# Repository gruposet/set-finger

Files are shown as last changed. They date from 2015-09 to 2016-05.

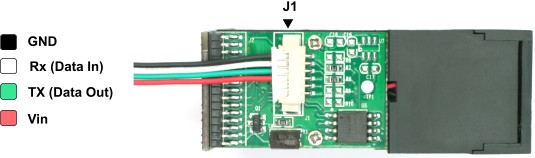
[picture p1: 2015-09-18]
software/codes/arduino/tests/fingerprint/ZFM-206SA_04.jpg

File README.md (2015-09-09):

# set-finger

GRUPO DE TRABALHO - SET

PROJETO SET-FINGER:

SET-FINGER é um projeto desenvolvido pelo Grupo de Trabalho - SET, com a
solução de uma tranca elétrica por biometria para segurança do espaço de
trabalho dos desenvolvedores e colaboradores do SET.

DESCRIÇÃO:

Os principais componentes do projeto são um Arduino Mega, um sensor
Biométrico, um teclado (4x3), shield Ethernet, relé, buzzer, display LCD
e um LED.

O repositório é composto pelos diretórios arduino code, board, libraries,
nodefinger e schematic. Pelo arquivos componentesSetFinger.pdf e README.txt

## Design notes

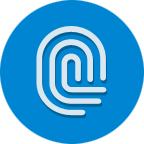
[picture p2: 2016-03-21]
software/codes/setfinger/sf.png

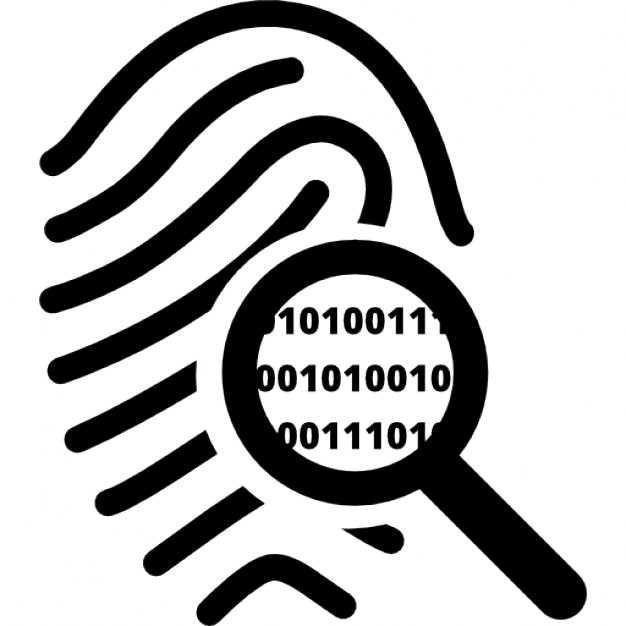
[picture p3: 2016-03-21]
software/codes/setfinger/fingerprint-search-symbol-of-secret-service-investigation_318-64591.png

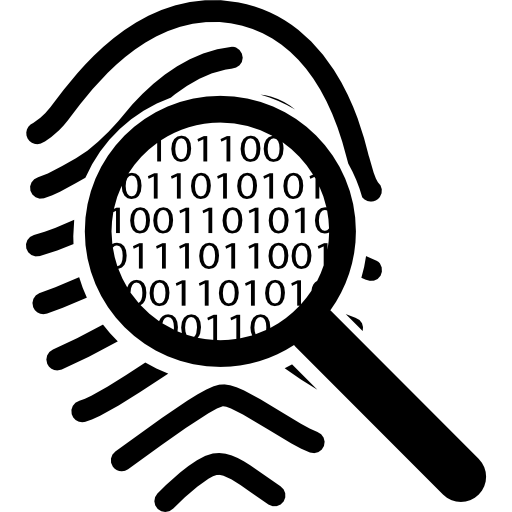
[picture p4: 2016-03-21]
software/codes/setfinger/sf1.png

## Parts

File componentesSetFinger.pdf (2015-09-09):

Componentes Set-Finger:

- Adafruit fingerprint sensor.
- Arduino Ethernet shield r3.
- Arduino mega 2560.
- Buzzer.
- Conetor P4 Fêmea.
- Diodo n4007.
- Display de lcd 16x2 com backlight.
- Fonte regulada 12V.
- Led RGB.
- Relé 5v.
- Resistor 100 ohm.
- Resistor 220 ohm.
- Resistor 2k2 ohm.
- Resistor 330 ohm.
- Resistor 68 ohm.
- Teclado matricial - 12 botões.

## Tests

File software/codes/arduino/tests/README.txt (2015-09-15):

Este diretório contém os diretórios de teste para cada componente do projeto com seus respectivos pinos.

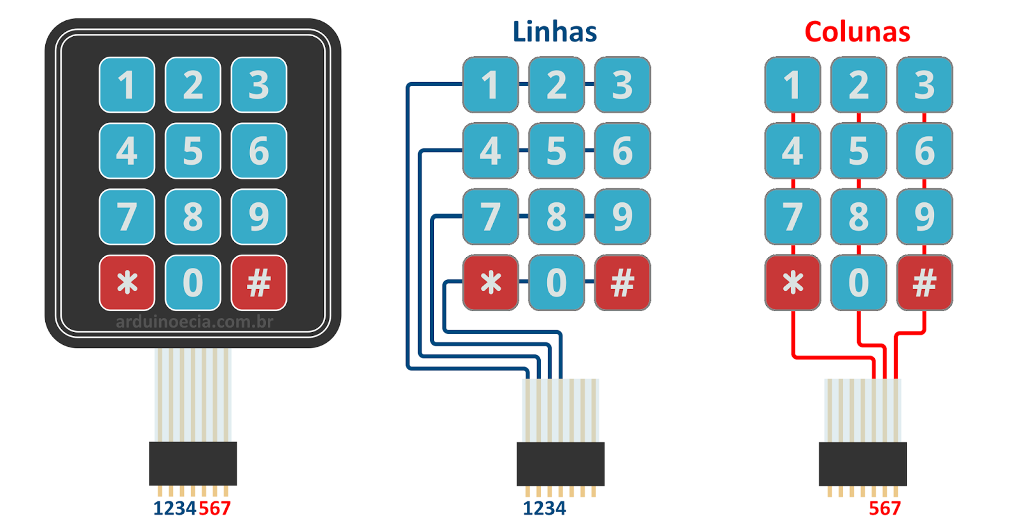
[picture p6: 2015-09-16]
software/codes/arduino/tests/keypad/Teclado_Matricial_4x3_linhas_e_colunas.png

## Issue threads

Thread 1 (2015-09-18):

Sensor fingerprint: Não funciona quando o código arduino é compilado na IDE 2:1.0.5+dfsg2-4

gruposet, 2015-09-18:
O sensor fingerprint não funciona quando o código é compilado e feito upload na IDE Arduino 2:1.0.5+dfsg2-4, apesar de não apresentar nenhum erro na compilação e upload. No entanto, percebemos que em outras versões da IDE Arduino o sensor funciona normalmente.

Closed 2015-09-18.

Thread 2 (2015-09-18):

Sensor fingerprint: Não funciona quando o código arduino é compilado na IDE 2:1.0.5+dfsg2-4

jeffersonfpalheta, 2015-09-18:
O sensor fingerprint não funciona quando o código é compilado e feito upload na IDE Arduino 2:1.0.5+dfsg2-4, apesar de não apresentar nenhum erro na compilação e upload. No entanto, percebemos que em outras versões da IDE Arduino o sensor funciona normalmente.

kelvinmaues, 2015-09-18:
Eu encontrei este fórum sobre o problema, não sei se ajuda.
http://forums.adafruit.com/viewtopic.php?f=25&t=38044&start=0

lucaslg26, 2015-09-20:
É uma package marcada como "unstable".
Para esse tipo de situação, evitem o uso de repositórios, ppa's e afins.
Baixem sempre o último build 'stable' do site oficial! :)

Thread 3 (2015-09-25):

Erro de impressão de mensagem no monitor serial Arduino

jeffersonfpalheta, 2015-09-25:
O código a seguir (Figura 1) executa a função [test( )] que retorna uma string. No loop é declarada uma variável que recebe o retorno da função teste e sem seguida esta variável é impressa na serial. No entanto, observasse um erro (Figura 2) na impressão da variável quando a função finger.getImage( ) é executada. O erro só é evitado de duas maneira:

[Solução 1]
Mudar o formato de retorno da função test( ) para [uint8_t], declarando assim: uint8_t test( )

[Solução 2]
Eliminar a função [finger.getImage( )]. Sem a execução desta função, a impressão da variável de retorno ocorre normalmente.

Figura 1 (código)
![Image of imagem5]
(https://lh3.googleusercontent.com/-fTIWpGMoyPE/VgVlG44bOpI/AAAAAAAABN8/QSN2o3Lke-I/s800-Ic42/imagem5.png)

Figura 2 (ERRO)
![Image of imagem6]
(https://lh3.googleusercontent.com/-EUJfj0hAlMU/VgVlIW_e6kI/AAAAAAAABOE/OPkDEjtmZUg/s800-Ic42/imagem6.png)

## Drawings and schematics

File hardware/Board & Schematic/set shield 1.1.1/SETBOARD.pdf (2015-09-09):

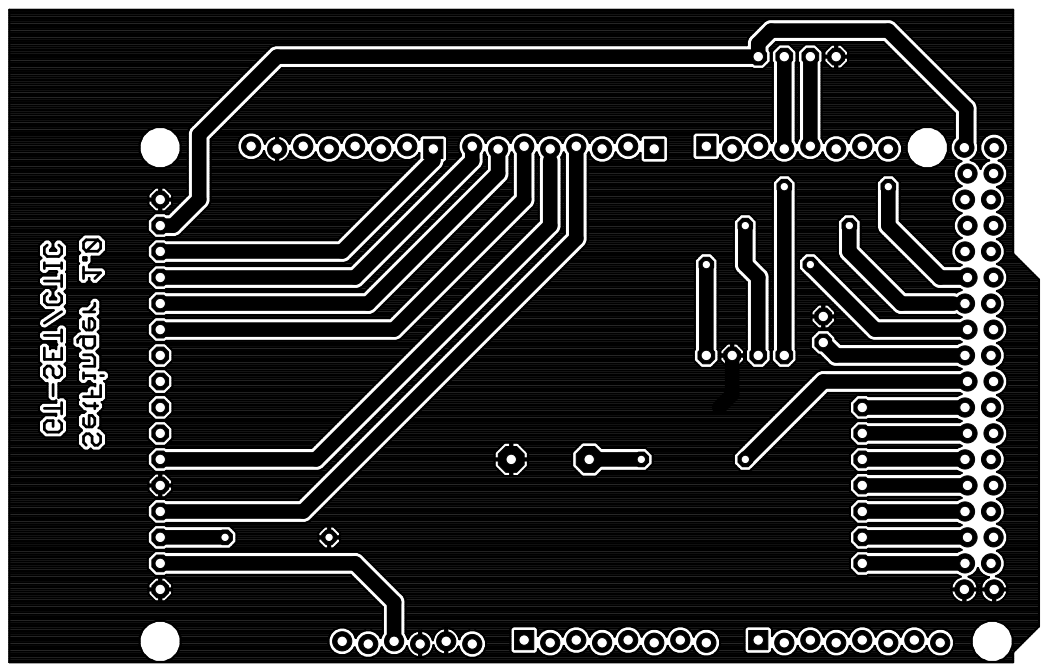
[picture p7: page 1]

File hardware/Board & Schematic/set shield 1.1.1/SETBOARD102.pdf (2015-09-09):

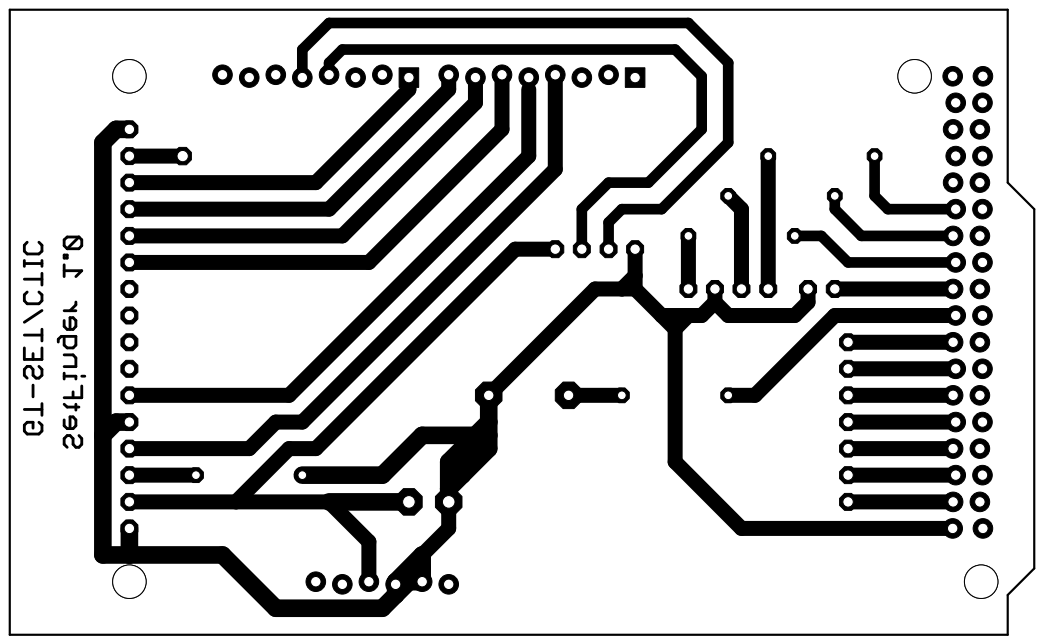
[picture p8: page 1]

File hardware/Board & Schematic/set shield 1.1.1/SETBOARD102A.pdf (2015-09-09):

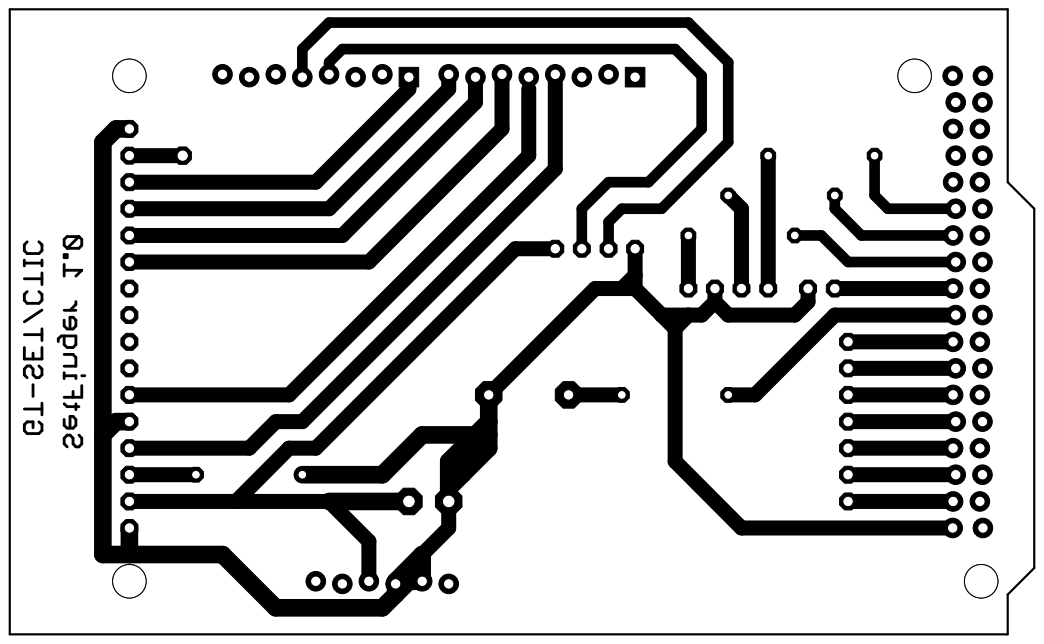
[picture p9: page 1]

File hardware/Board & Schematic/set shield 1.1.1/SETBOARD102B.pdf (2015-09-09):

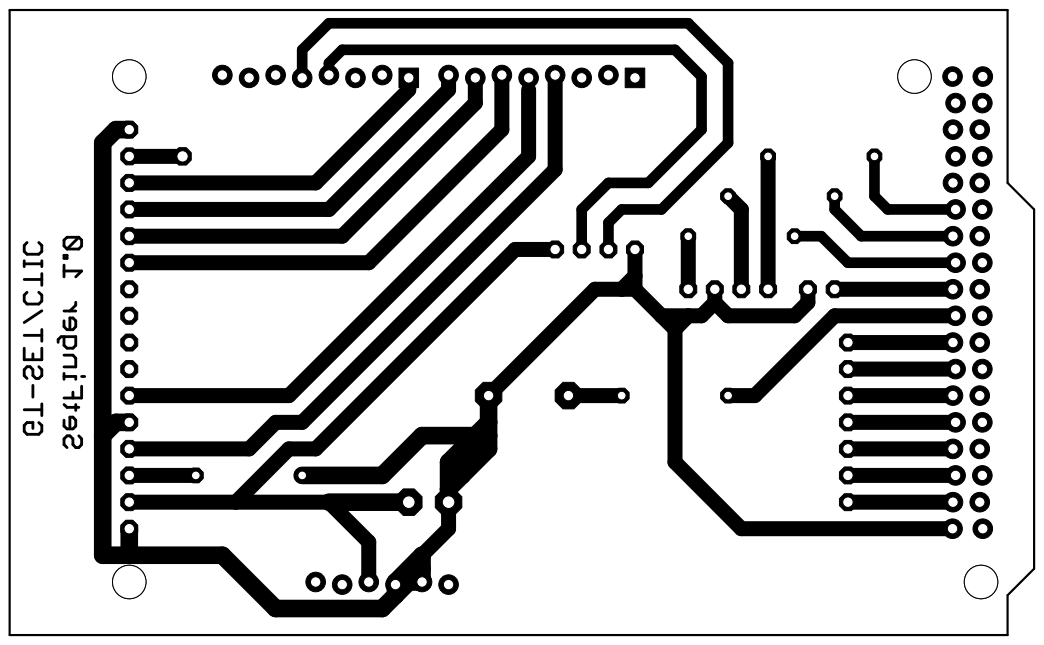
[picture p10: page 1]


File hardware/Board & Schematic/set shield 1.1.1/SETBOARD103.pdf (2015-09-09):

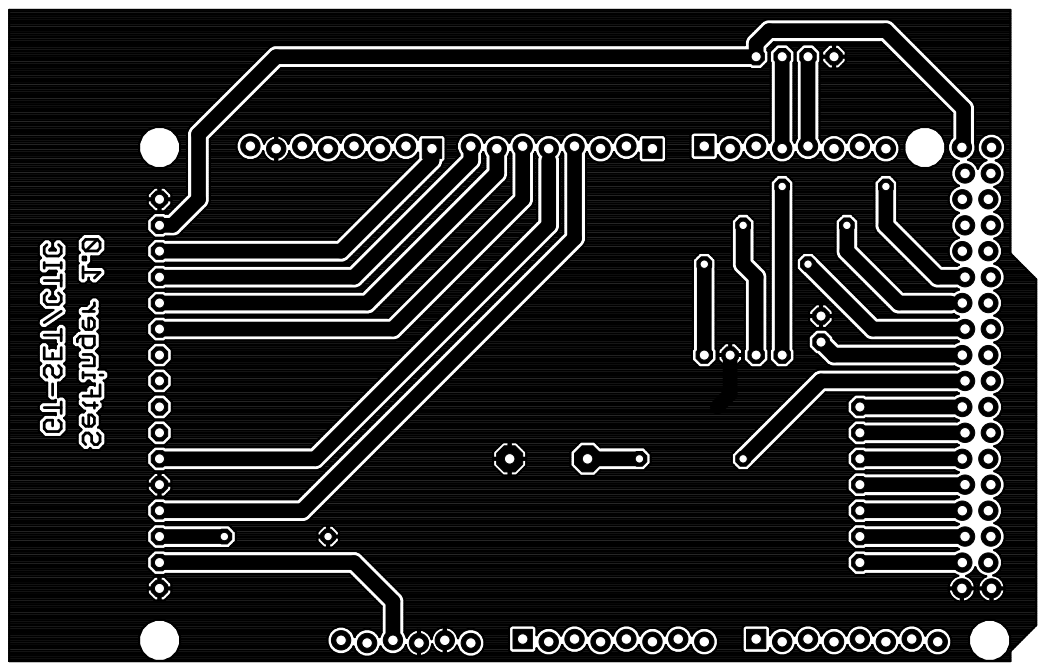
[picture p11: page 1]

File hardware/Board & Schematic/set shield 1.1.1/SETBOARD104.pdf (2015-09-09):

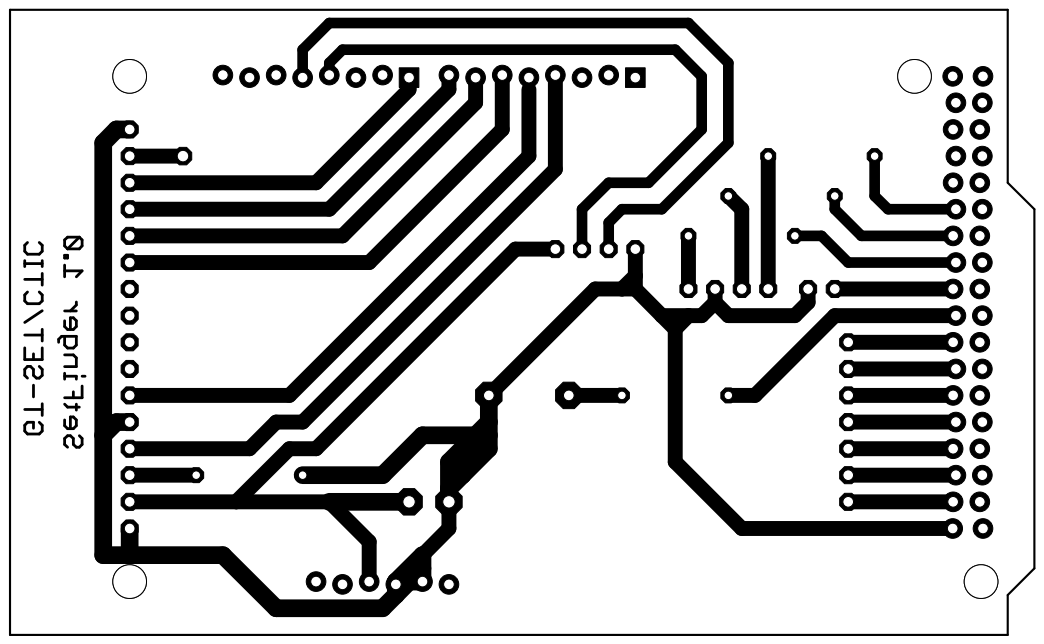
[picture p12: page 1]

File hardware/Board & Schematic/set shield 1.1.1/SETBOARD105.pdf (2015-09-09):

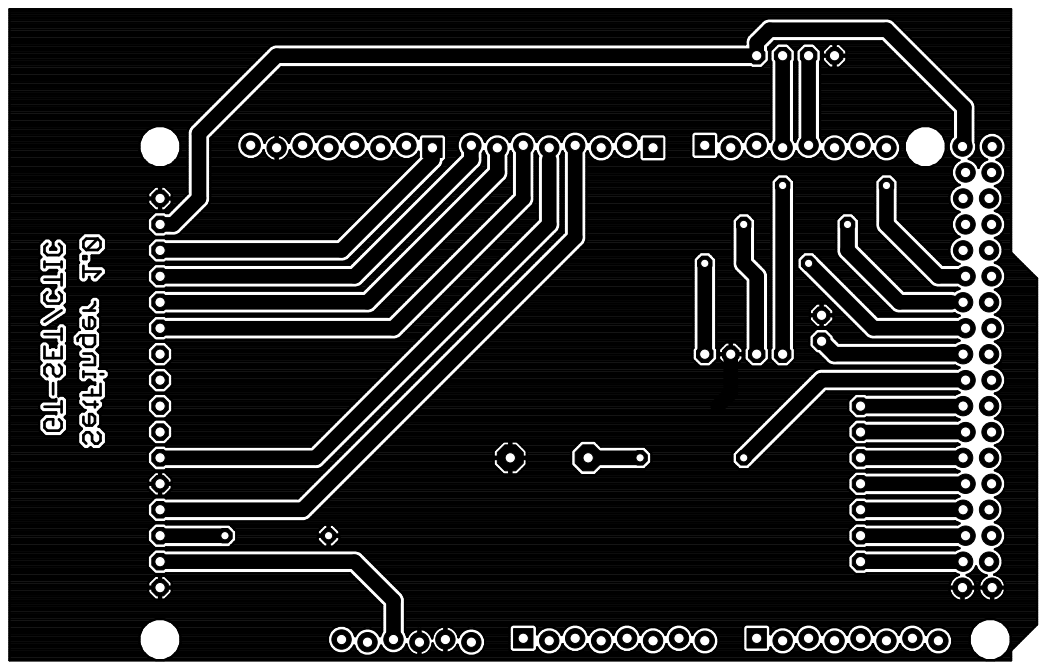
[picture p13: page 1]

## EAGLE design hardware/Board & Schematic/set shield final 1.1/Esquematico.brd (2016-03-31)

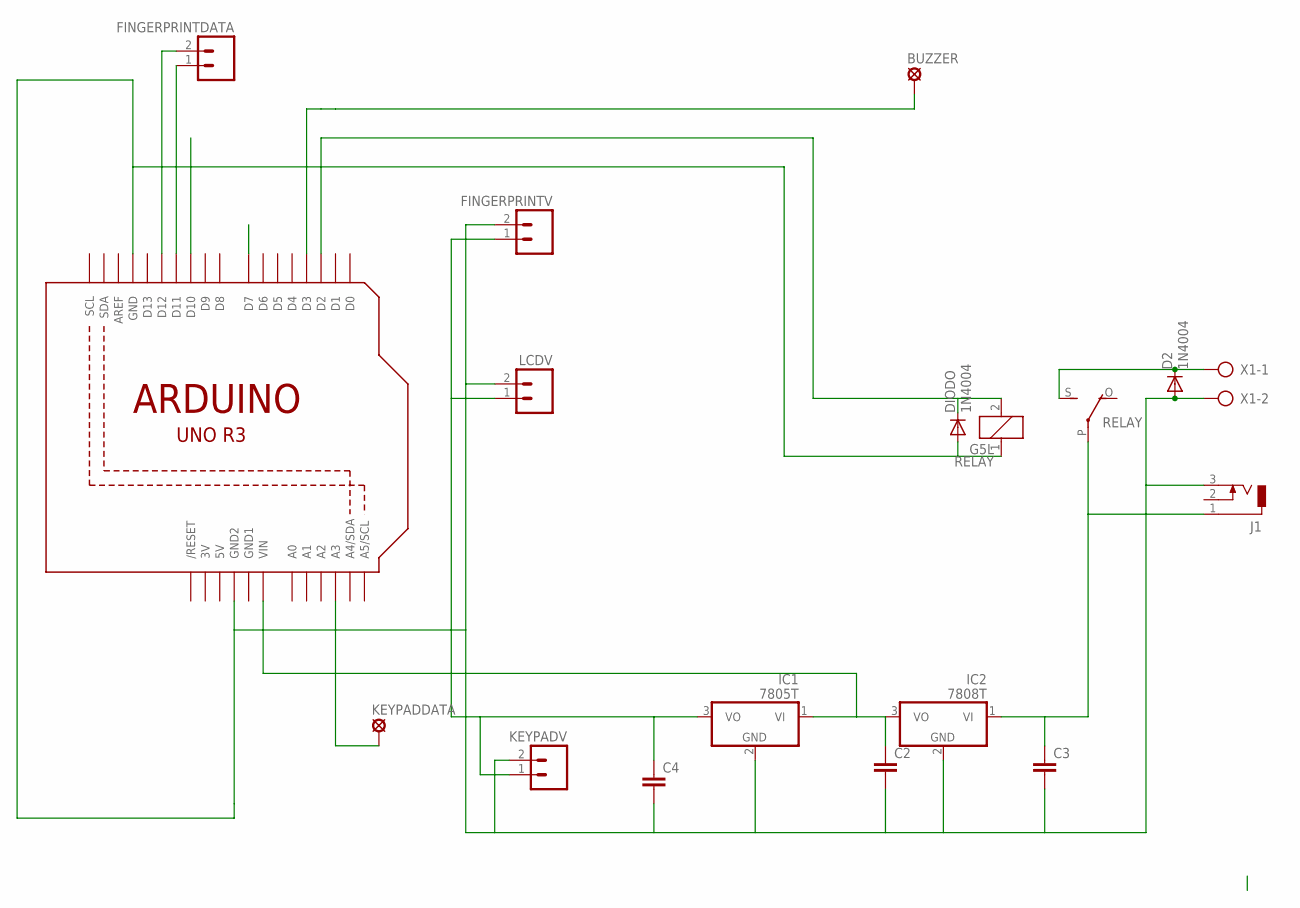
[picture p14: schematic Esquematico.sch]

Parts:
BUZZER: SE14
C2, C3, C4: C-EU025-030X050; C025-030X050
D2: 1N4004; DO41-10
DIODO: 1N4004; DO41-10
FINGERPRINTDATA: M02; 02P
FINGERPRINTV: M02; 02P
IC1: 7805T; TO220H
IC2: 7808T; TO220H
J1: DCJ0303
KEYPADDATA: SE14
KEYPADV: M02; 02P
LCDV: M02; 02P
Q1: ARDUINOR3-NOIOREF-NOTEXT; ARDUINOR3-NOTEXT-NOIOREF
RELAY: G5L; G5LE
X1: AK300/2

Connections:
3V: Q1.3V
5V: Q1.5V
GND1: Q1.GND1
unnamed: FINGERPRINTDATA.2, Q1.D12
unnamed: FINGERPRINTDATA.1, Q1.D11
unnamed: D2.C, RELAY.S, X1.1
unnamed: KEYPADDATA.MP, Q1.A3
unnamed: BUZZER.MP, Q1.D3
unnamed: C4.1, FINGERPRINTV.1, IC1.3 (VO), KEYPADV.1, LCDV.1
unnamed: DIODO.C, Q1.D2, RELAY.2
unnamed: DIODO.A, Q1.GND, RELAY.1
unnamed: C2.2, C3.2, C4.2, D2.A, FINGERPRINTV.2, IC1.2 (GND), IC2.2 (GND), J1.3, KEYPADV.2, LCDV.2, Q1.GND2, X1.2
unnamed: C2.1, IC1.1 (VI), IC2.3 (VO), Q1.VIN
unnamed: C3.1, IC2.1 (VI), J1.1, RELAY.P

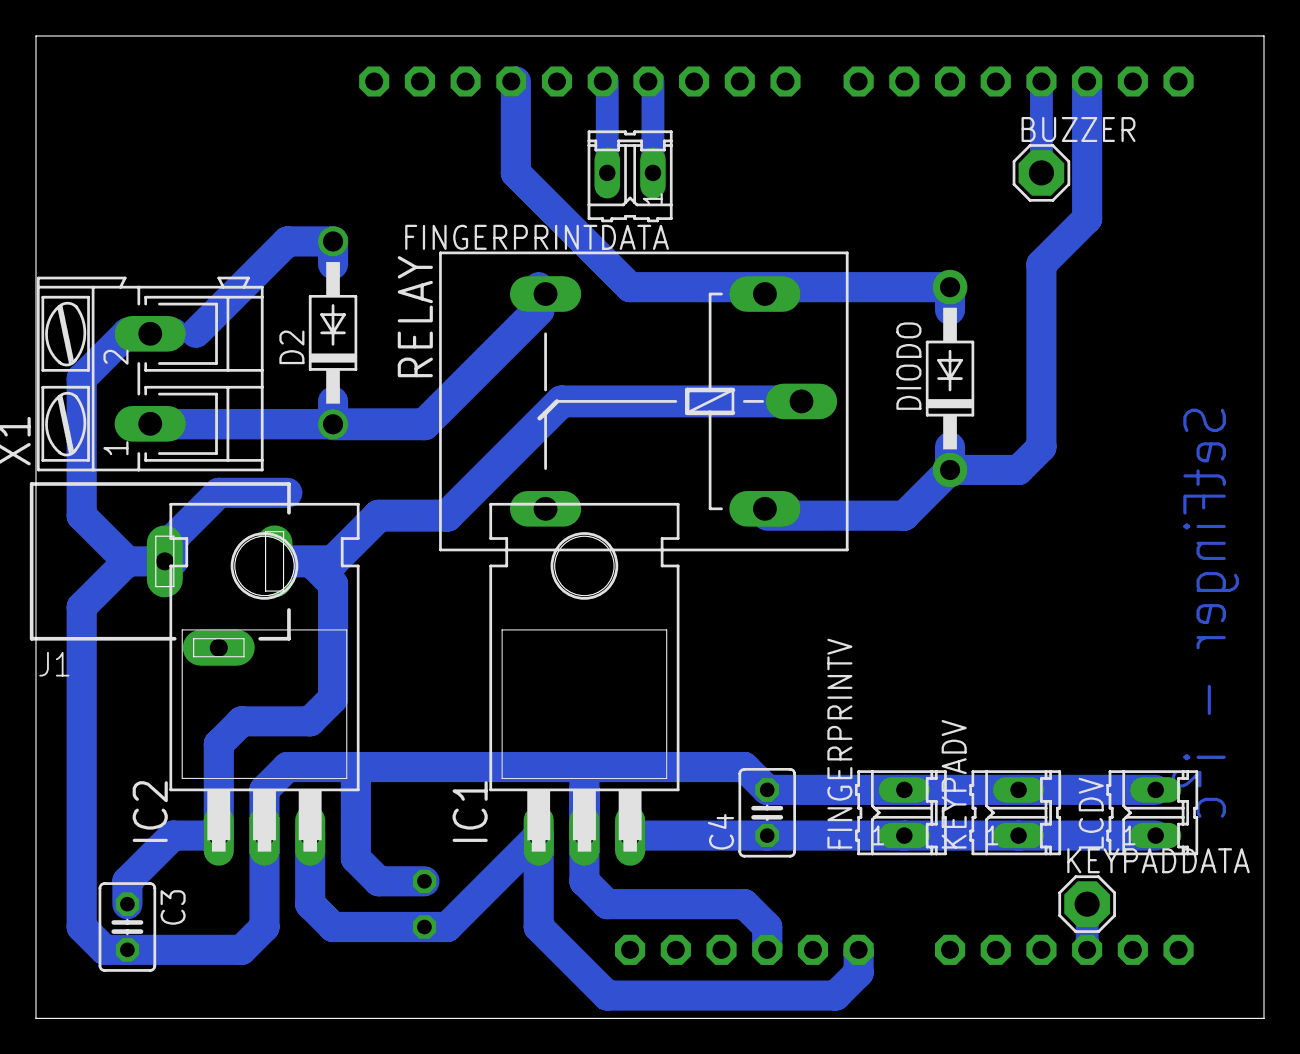
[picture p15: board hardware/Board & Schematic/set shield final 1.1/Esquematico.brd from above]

Board: 2 copper layers, 68.2 x 54.6 mm, 17 parts (1 on the bottom side), 11 nets.

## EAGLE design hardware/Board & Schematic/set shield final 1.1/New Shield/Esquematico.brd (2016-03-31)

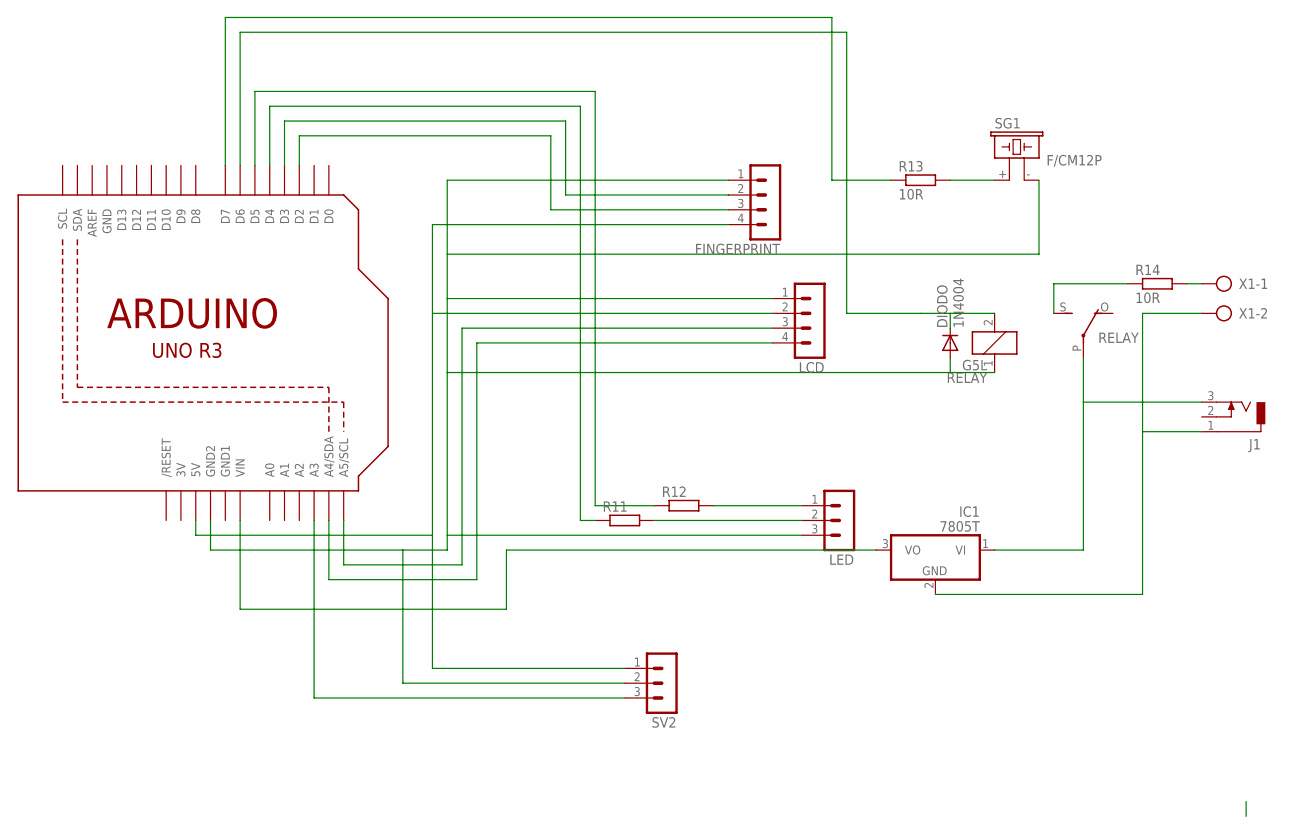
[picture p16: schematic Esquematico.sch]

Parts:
DIODO: 1N4004; DO41-10
FINGERPRINT: MA04-1
IC1: 7805T; TO220H
J1: DCJ0303
LCD: MA04-1
LED: MA03-1
Q1: ARDUINOR3-NOIOREF-NOTEXT; ARDUINOR3-NOTEXT-NOIOREF
R11, R12: R-EU_0309/10; 0309/10
R13: 10R; 0309/10
R14: 10R; P0817/22
RELAY: G5L; G5LE
SG1: F/CM12P
SV2: MA03-1
X1: AK300/2

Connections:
3V: Q1.3V
GND: Q1.GND
GND1: Q1.GND1
unnamed: FINGERPRINT.4, LCD.2, Q1.5V, SV2.1
unnamed: DIODO.A, FINGERPRINT.1, LCD.1, LED.3, Q1.GND2, RELAY.1, SG1.- (2), SV2.2
unnamed: FINGERPRINT.3, Q1.D2
unnamed: FINGERPRINT.2, Q1.D3
unnamed: LCD.3, Q1.A5 (A5/SCL)
unnamed: LCD.4, Q1.A4 (A4/SDA)
unnamed: DIODO.C, Q1.D6, RELAY.2
unnamed: Q1.D4, R11.1
unnamed: Q1.D5, R12.1
unnamed: Q1.D7, R13.1
unnamed: R14.2, X1.1
unnamed: IC1.2 (GND), J1.1, X1.2
unnamed: IC1.1 (VI), J1.3, RELAY.P
unnamed: R14.1, RELAY.S
unnamed: IC1.3 (VO), Q1.VIN
unnamed: R13.2, SG1.+ (1)
unnamed: LED.1, R12.2
unnamed: LED.2, R11.2
unnamed: Q1.A3, SV2.3

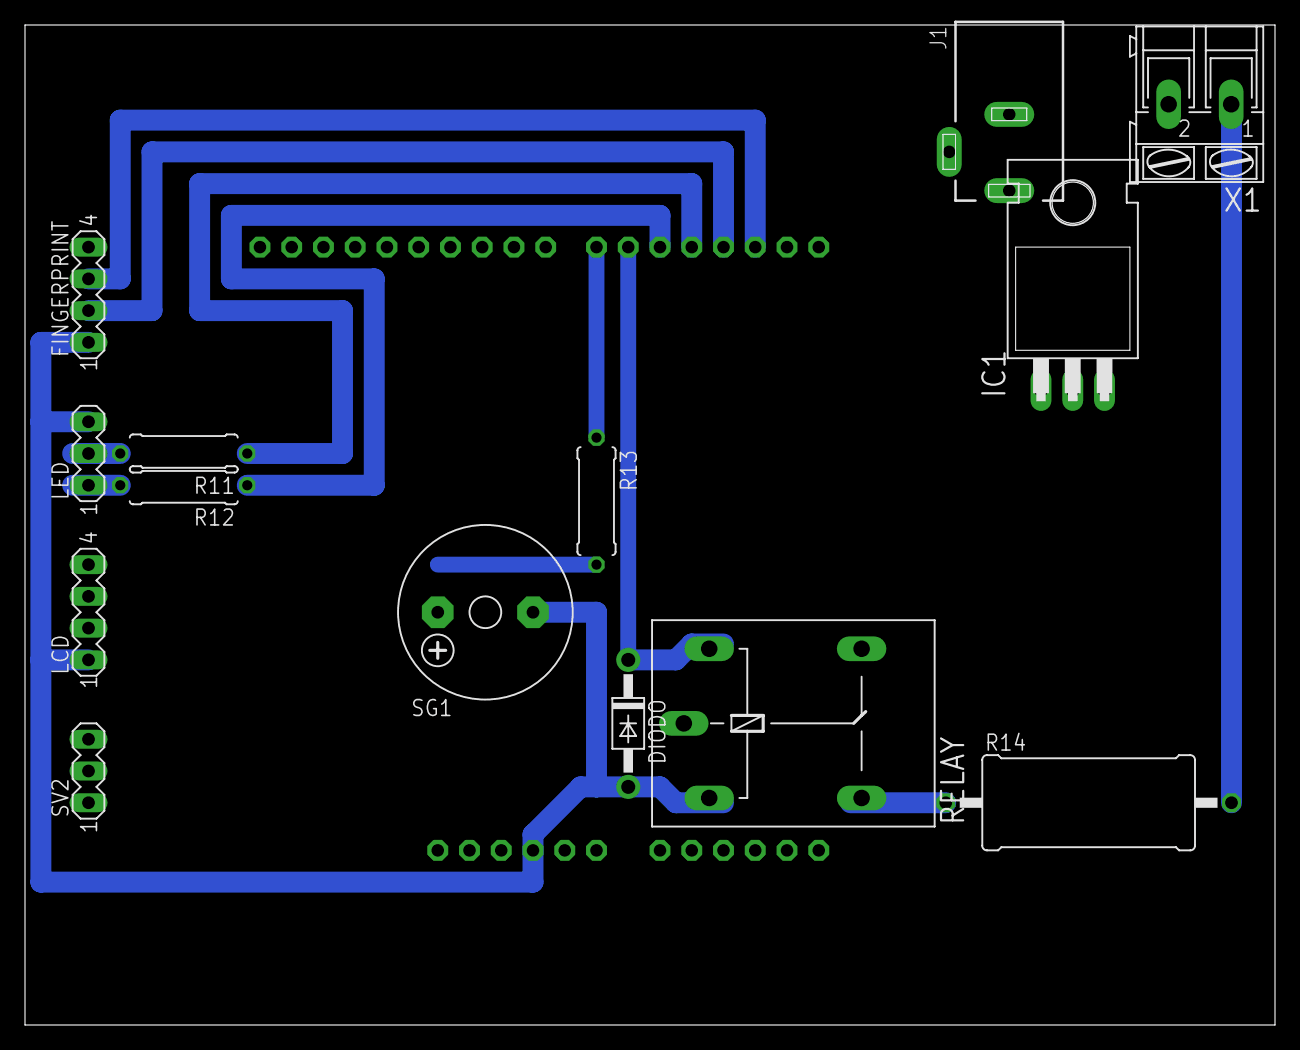
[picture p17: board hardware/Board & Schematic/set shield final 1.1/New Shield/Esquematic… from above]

Board: 2 copper layers, 100.0 x 80.0 mm, 15 parts (0 on the bottom side), 19 nets.

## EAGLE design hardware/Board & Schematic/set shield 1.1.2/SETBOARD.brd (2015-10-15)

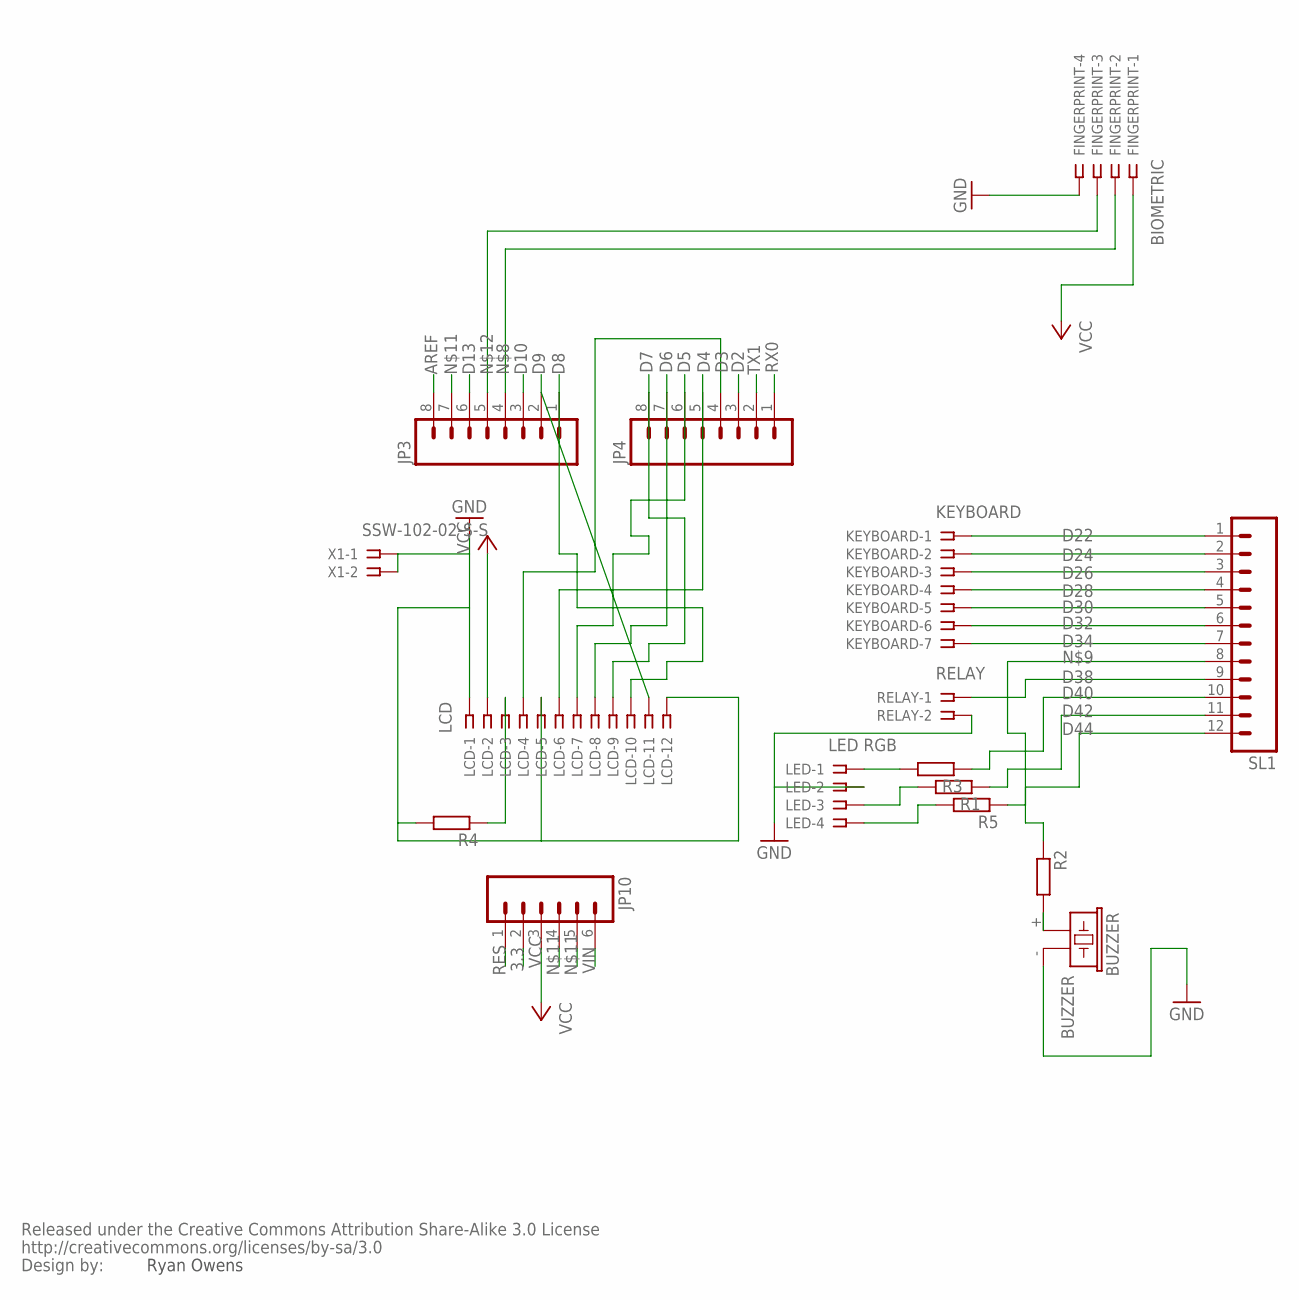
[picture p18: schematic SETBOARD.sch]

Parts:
BUZZER: BUZZER; F/CM12P
FINGERPRINT: BIOMETRIC; SSW-104-02-S-S
JP3, JP4: M08LOCK; 1X08_LOCK
JP10: M06LOCK; 1X06_LOCK
KEYBOARD: KEYBOARD; SSW-107-02-S-S
LCD: LCD; SSW-112-02-S-S
LED: LED RGB; SSW-104-02-S-S
R1, R2, R3, R4, R5: R0207/10; 0207/10
RELAY: RELAY; SSW-102-02-S-S
SL1: M12; 12P
U$2: CREATIVE_COMMONS
X1: SSW-102-02-S-S

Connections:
3.3: JP10.2
AREF: JP3.8
D2: JP4.3
D3: JP4.4, LCD.4
D4: JP4.5, LCD.6
D5: JP4.6, LCD.7
D6: JP4.7, LCD.8
D7: JP4.8, LCD.9
D8: JP3.1, LCD.10
D9: JP3.2, LCD.11
D10: JP3.3
D13: JP3.6
D22: KEYBOARD.1, SL1.1
D24: KEYBOARD.2, SL1.2
D26: KEYBOARD.3, SL1.3
D28: KEYBOARD.4, SL1.4
D30: KEYBOARD.5, SL1.5
D32: KEYBOARD.6, SL1.6
D34: KEYBOARD.7, SL1.7
D38: RELAY.1, SL1.9
D40: R3.1, SL1.10
D42: R1.1, SL1.11
D44: R5.1, SL1.12
unnamed: LCD.3, R4.1
unnamed: LED.1, R3.2
unnamed: LED.3, R1.2
unnamed: LED.4, R5.2
unnamed: BUZZER.+ (1), R2.2
unnamed: FINGERPRINT.2, JP3.4
unnamed: R2.1, SL1.8
unnamed: BUZZER.- (2), FINGERPRINT.4, JP3.7, JP10.4, JP10.5, LCD.1, LCD.5, LCD.12, LED.2, R4.2, RELAY.2, X1.1, X1.2
unnamed: FINGERPRINT.3, JP3.5
RES: JP10.1
RX0: JP4.1
TX1: JP4.2
VCC: FINGERPRINT.1, JP10.3, LCD.2
VIN: JP10.6

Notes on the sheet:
Ryan Owens

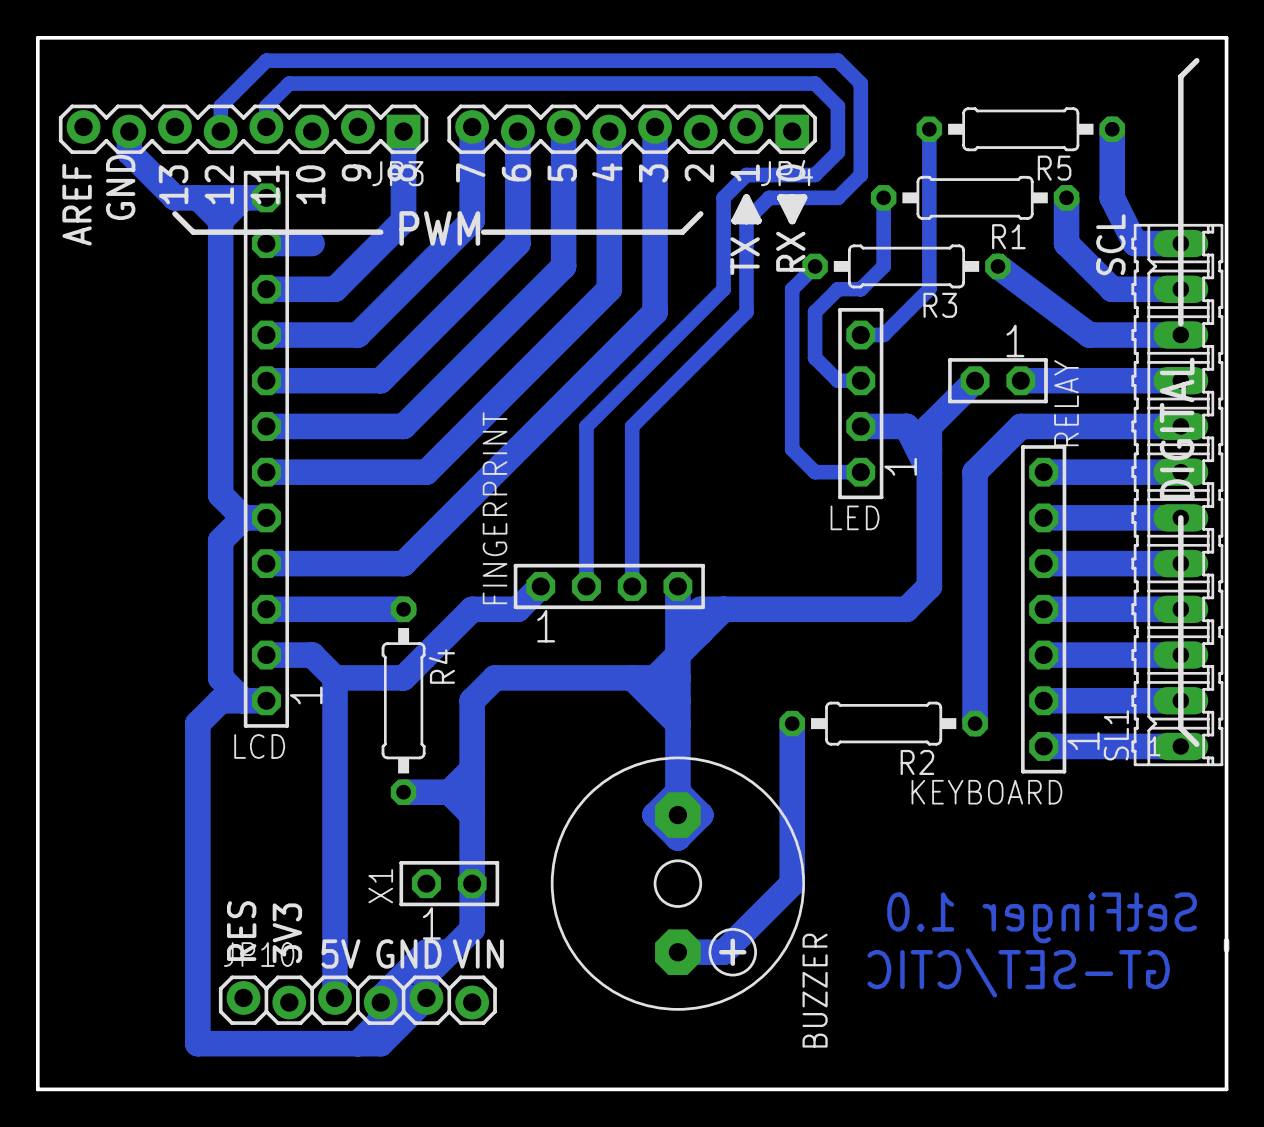
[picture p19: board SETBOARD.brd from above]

Board: 2 copper layers, 66.0 x 58.4 mm, 17 parts (0 on the bottom side), 28 nets.

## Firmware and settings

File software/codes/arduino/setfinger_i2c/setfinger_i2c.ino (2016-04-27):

/*>>>>>>>>>>>>>>>>>>>>>>>>>>>>>>>>>>>>>>>>>>>>>>>>> Bibliotecass e Configurações >>>>>>>>>>>>>>>>>>>>>>>>>>>>>>>>>>>>>>>>>>>>>>>>>*/

/*-----------------------inclusão de biblioteca ethernet shield--------------------*/
#include <SPI.h>
#include <Ethernet.h>
byte mac[] = { 0xDE, 0xAD, 0xBE, 0xEF, 0xFE, 0xED };
IPAddress serverIP(192, 168, 14, 22); // endereço IP da máquina servidor node.js
const int serverPort = 7000; //porta fonte pode ser de 1-65535

// Inicializa biblioteca ethernet cliente
EthernetClient client;

/*-------------inclusão de biblioteca do sensor fingerprint----------------*/
#include <Adafruit_Fingerprint.h>
//decisão de biblioteca a ser utilizada de acordo com a versão da IDE
#if ARDUINO >= 100
#include <SoftwareSerial.h>
SoftwareSerial mySerial(11, 12);
#else
#include <NewSoftSerial.h>
NewSoftSerial mySerial(11, 12);
#endif

//Declaração do objeto para comunicação.
Adafruit_Fingerprint finger = Adafruit_Fingerprint(&mySerial);

/*-------------inclusão de biblioteca de LCD-----------*/
#include <Wire.h>
#include <LiquidCrystal_I2C.h>

// Inicializa o display no endereco 0x27
LiquidCrystal_I2C lcd(0x27, 2, 1, 0, 4, 5, 6, 7, 3, POSITIVE);



/*-------------Definindo os pinos do LED RGB-------------------*/
#define red 26    //define o pino do LED como vermelho
#define green 24   // define o pino do LED como verde
#define blue 22   //define o pino do LED como azul


/*-------------Definindo o pino do buzzer e relé---------------*/
int const buzzer = 30;
int const rele = 28;
/*------------------------------------------------------------*/
#include <Keypad_I2C.h>
#include <Keypad.h>
#define I2CADDR 0x38
const byte ROWS = 4; //four rows
const byte COLS = 4; //three columns
char keys[ROWS][COLS] = {
  {'1', '2', '3', 'A'},
  {'4', '5', '6', 'B'},
  {'7', '8', '9', 'C'},
  {'*', '0', '#', 'D'}
};
// Digitran keypad, bit numbers of PCF8574 i/o port
byte rowPins[ROWS] = {0, 1, 2, 3}; //connect to the row pinouts of the keypad
byte colPins[COLS] = {4, 5, 6, 7}; //connect to the column pinouts of the keypad
Keypad_I2C kpd( makeKeymap(keys), rowPins, colPins, ROWS, COLS, I2CADDR, PCF8574 );
/*-------------Inclusão de biblioteca e configuração do teclado matricial 4x3(Keypad)----------*/


/*-------------------------Declaração de variáveis de estado (flag)-------------------------*/
#include <ArduinoJson.h>
String SETFINGER_HWID = "GT-SET";       //Identificação do dispositivo SF para o servidor
String welcomeName;                     //Nome de boas-vindas que o dispositivo SF recebe do serivodr
bool AuthOk = false;                    //Viariável que identifica se o dispositivo SF foi autenticado com sucesso pelo servidor
bool waitingResponse = false;           //Variável que indica se o dispositivo SF está aguardando alguma resposta do servidor
bool waitingKeyboard = false;           //Variável que indica se o dispositivo SF está aguardando algum comando do teclado
bool waitingID = false;                 //Variável que indica se o dispositivo SF está aguardando que o servidor responda o ID a ser atribuido para a digital que será gravada no sensor
bool fullCircle = true;                 //Variável que indica se todos os passos foram executados, para retornar ao estado principal

String userName; //armazena o nome fornecido pelo servidor até

/*>>>>>>>>>>>>>>>>>>>>>>>>>>>>>>>>>>>>>>>>>>>>>>>>> SETUP >>>>>>>>>>>>>>>>>>>>>>>>>>>>>>>>>>>>>>>>>>>>>>>>>*/
void setup() {

  Wire.begin( );
  kpd.begin( makeKeymap(keys) );
  Serial.begin(9600);

  finger.begin(57600);// Define a taxa de dados para a porta serial do sensor


  lcd.begin (16, 2);
  lcd.setBacklight(HIGH);

  pinMode(red, OUTPUT);   //define red Pin como saída
  pinMode(green, OUTPUT);//define green Pin como saída
  pinMode(blue, OUTPUT);//define bluePin como saída

  pinMode(buzzer, OUTPUT); //define pino do buzzer como saída
  pinMode(rele, OUTPUT); //define pino do relé como saída

  Ethernet.begin(mac);
  while (!Serial) {
    ; // wait for serial port to connect. Needed for Leonardo only
  }
  delay(1000);
  serverConnect();


}



/*>>>>>>>>>>>>>>>>>>>>>>>>>>>>>>>>>>>>>>>>>>>>>>>>> LOOP >>>>>>>>>>>>>>>>>>>>>>>>>>>>>>>>>>>>>>>>>>>>>>>>>*/
void loop() {

  if (AuthOk) {

    if (waitingKeyboard) {          //Função usada para o menu de administrador, ela recebe os comandos do teclado e executa uma função a partir de uma tecla específica
      char tecla = leitura();         
      Serial.print("tecla: ");
      Serial.println(tecla);
      if (tecla == '1') {      
        Serial.print("opendoor");
        Serial.print(tecla);
        openDoor();           //Se for pressionada a tecla 1, o relé é acionado.
        fullCircle = true;
      }
      if (tecla == '2') {
        registerFinger(0);        //Se for pressionada a tecla 2, a função de registro de usuário é chamada
      }


      waitingKeyboard = false;    //No final de cada ciclo acima, a variável de flag do teclado é setada como falsa.

    }



    if (fullCircle && !waitingKeyboard && !waitingID) {
      lcd.clear(); // limpa o conteúdo no dysplay LCD
      lcd.setCursor(0, 0); // seta o cursor para: (coluna = 0, linha = 0)
      lcd.print("BEM-VINDO(A) AO");
      lcd.setCursor(0, 1); // seta para linha 1, ou seja, a linha de baixo
      lcd.print(welcomeName);
      fullCircle = false;
    }
    if (!waitingResponse && !waitingKeyboard && !waitingID) {   //Estado padrão da tranca, sempre executado enquanto a tranca estiver ociosa
      int fingerID = readFinger();
      if (fingerID) {
        sendFingerID(fingerID);
        waitingResponse = true;
      }
    }
  }




  readTCPStream();              //Chamada de função que lê constantemente o que é enviado pelo servidor

  if (!client.connected()) {    //É executado quando a conexão entre a tranca e o servidor é perdida
    Serial.println("Disconnected!");
    serverConnect();

  }
}

/*|||||||||||||||||||||||||||||||||||||||||||||||||||||||||||||||FUNÇÕES|||||||||||||||||||||||||||||||||||||||||||||||||||||||||||||||*/


void serverConnect() {  //estabelece uma conexão TCP com o servidor e envia a mensagem de "boas-vindas"
  client.stop();
  AuthOk = false;
  Serial.println("Connecting...");
  printMessage("CONECTANDO...", "");
  if (client.connect(serverIP, serverPort)) {
    Serial.println("Connected!");

    StaticJsonBuffer<64> jsonBuffer;                    //Etapa de criação de uma string JSON
    JsonObject& root = jsonBuffer.createObject();
    root["type"] = "conn";
    root["hwid"] = SETFINGER_HWID;
    char buffer[64];
    root.printTo(buffer, sizeof(buffer)); //transforma um objeto json em uma string json e armazena na variavel buffer
    client.print(buffer);

    fullCircle = false;
    waitingResponse = false;
    waitingKeyboard = false;
  } else {
    printMessage("ERRO", "ID: #0001");
    Serial.println("Connection failed!");
    redColorAlert();
  }
}





/*>>>>>>>>>>>>>>>>>>>>>>>>>>>>>>>>>>>>>>>>>>>>>>>>> Grava digitais no sensor fingerprint >>>>>>>>>>>>>>>>>>>>>>>>>>>>>>>>>>>>>>>>>>>>>>>>>*/
uint8_t addFinger(uint8_t id) {
  Serial.println("Procurando sensor...");
  if (finger.verifyPassword()) {
    Serial.println("Sensor FingerPrint Encontrado!");
    delay(1000);
  }
  else {
    Serial.println("Nenhum sensor foi encontrato. Conecte um sensor!");
    delay(1000);
    addFinger(0);
  }
  uint8_t digital;


  lcd.clear(); // limpa o conteúdo no dysplay LCD
  lcd.setCursor(0, 0); // seta o cursor para: (coluna = 0, linha = 0)
  lcd.print("Coloque o dedo");
  delay(1000);

  digital = finger.getImage();
  while (digital != FINGERPRINT_OK) {
    digital = finger.getImage();
  }

  digital = finger.image2Tz(1);
  if (digital != FINGERPRINT_OK)
    return -1; //retorna -1 e sai da função addFinger() somente se a conversão da imagem da primeira digital não tiver ocorrido com sucesso

  digital = finger.getImage();
  while (digital != FINGERPRINT_OK) {
    digital = finger.getImage();
  }

  //converte a imagem da segunda digital lida em arquivo caracter
  digital = finger.image2Tz(2);
  if (digital != FINGERPRINT_OK)  return -1; //retorna -1 e sai da função addFinger() somente se a conversão da imagem da segunda digital não tiver ocorrido com sucesso
  //criação do modelo para a digital lida

  digital = finger.createModel();
  if (digital != FINGERPRINT_OK) {
    lcd.clear(); // limpa o conteúdo no dysplay LCD
    lcd.setCursor(0, 0); // seta o cursor para: (coluna = 0, linha = 0)
    lcd.print("TENTE NOVAMENTE!");
    client.print("{\"type\":\"registerfail\"}");
    return -1;
  }
  //Serial.println("MODELO CRIADO COM SUCESSO. DIGITAIS COMPATIVEIS");
  delay(1000);
  //gravação do modelo da digital

  digital = finger.storeModel(id);

  lcd.clear(); // limpa o conteúdo no dysplay LCD
  lcd.setCursor(0, 0); // seta o cursor para: (coluna = 0, linha = 0)
  lcd.print("Usuario OK");
  client.print("{\"type\":\"registerok\"}");
  greenColorAlert();
  delay(1000);
  return 0;

}



/*>>>>>>>>>>>>>>>>>>>>>>>>>>>>>>>>>>>>>>>>>>>>>>>>> Leitura e autenticação de digitais >>>>>>>>>>>>>>>>>>>>>>>>>>>>>>>>>>>>>>>>>>>>>>>>>*/
int readFinger() {
  //Serial.println("Procurando sensor...");
  if (finger.verifyPassword()) {
    //Serial.println("Sensor FingerPrint Encontrado!");
  }
  else {
    //Serial.println("Nenhum sensor foi encontrato. Conecte um sensor!");
  }
  uint8_t digital;
  //Serial.println("Aguardando uma digital valida. Coloque seu dedo...");
  digital = finger.getImage();
  if (digital != FINGERPRINT_OK) {
    digital = finger.getImage();
  }

  if (digital == FINGERPRINT_OK) {
    digital = finger.image2Tz();
    if (digital != FINGERPRINT_OK)
      return -1; //retorna -1 e sai da função addFinger() somente se a conversão da imagem da digital não tiver ocorrido com sucesso
    digital = finger.fingerFastSearch();
    if (digital != FINGERPRINT_OK) {
      //Serial.println("DIGITAL NAO ENCONTRADA. TENTE NOVAMENTE!");
      return -1; //retorna -1 e sai da função addFinger() somente se a digital for reconhecida entre as digitais presentes no sensor
    }
    return finger.fingerID;
  }
  return 0;
}

/*>>>>>>>>>>>>>>>>>>>>>>>>>>>>>>>>>>>>>>>>>>>>>>>>> Exclusão de digitais >>>>>>>>>>>>>>>>>>>>>>>>>>>>>>>>>>>>>>>>>>>>>>>>>*/
uint8_t deleteFinger(uint8_t id) {
  uint8_t digital;
  digital = finger.deleteModel(id);
  if (digital == FINGERPRINT_OK) {
    Serial.print("Digital ID:");
    Serial.print(id);
    Serial.println(" Excluida com Sucesso!");
  } else {
    Serial.print("ERRO!NÃO FOI POSSIVEL EXCLUIR A DIGITAL ID: ");
    Serial.println(id);
  }
}

/*>>>>>>>>>>>>>>>>>>>>>>>>>>>>>>>>>>>>>>>>>>>>>>>>> Imprime mensagem no display LCD >>>>>>>>>>>>>>>>>>>>>>>>>>>>>>>>>>>>>>>>>>>>>>>>>*/
void printMessage(String row1, String row2) {
  lcd.clear(); // limpa o conteúdo no dysplay LCD
  lcd.setCursor(0, 0); // seta o cursor para: (coluna = 0, linha = 0)
  lcd.print(row1);
  lcd.setCursor(0, 1); // seta para linha 1, ou seja, a linha de baixo
  lcd.print(row2);
}

/*>>>>>>>>>>>>>>>>>>>>>>>>>>>>>>>>>>>>>>>>>>>>>>>>> Led e Buzzer - sinal alerta vermelho >>>>>>>>>>>>>>>>>>>>>>>>>>>>>>>>>>>>>>>>>>>>>>>>>*/
void redColorAlert() { //significa usuário não autorizado ou acesso negado
  short int i = 0;
  for (i = 0; i < 2; i++) {
    digitalWrite(blue, LOW);
    digitalWrite(green, LOW);
    digitalWrite(red, HIGH);
    tone(buzzer, 1400, 1000);
    delay(1000);
    digitalWrite(red, LOW);
    delay(100);
  }
}

/*>>>>>>>>>>>>>>>>>>>>>>>>>>>>>>>>>>>>>>>>>>>>>>>>> Led e Buzzer - sinal de alerta verde >>>>>>>>>>>>>>>>>>>>>>>>>>>>>>>>>>>>>>>>>>>>>>>>>*/
void greenColorAlert() { //significa usuário autorizado ou tudo ok!
  short int i = 0;
  for (i = 0; i < 2; i++) {
    digitalWrite(blue, LOW);
    digitalWrite(red, LOW);
    digitalWrite(green, HIGH);
    tone(buzzer, 750, 500);
    delay(500);
    digitalWrite(green, LOW);
    delay(50);
  }
}

/*>>>>>>>>>>>>>>>>>>>>>>>>>>>>>>>>>>>>>>>>>>>>>>>>> Led e Buzzer - sinal de alerta azul >>>>>>>>>>>>>>>>>>>>>>>>>>>>>>>>>>>>>>>>>>>>>>>>>*/
void blueColorAlert() { //significa usuário admin autorizado ou conexão com o servidor.
  short int i = 0;
  for (i = 0; i < 2; i++) {
    digitalWrite(green, LOW);
    digitalWrite(red, LOW);
    digitalWrite(blue, HIGH);
    tone(buzzer, 500, 300);
    delay(25);
    digitalWrite(blue, LOW);
    delay(250);
  }
}




void handleConnEvents(const char* msg, String name) { //trata a mensagem de conexão recebida do servidor
  if (strcmp(msg, "fail") == 0) {                  //Executado quando há falha de autenticação com o servidor
    printMessage("ERRO", "ID: #0002");
    redColorAlert();
    Serial.println("Auth fail! Reconnecting...");
    delay(5000);
    AuthOk = false;
    client.stop();
  }
  else if (strcmp(msg, "ok") == 0) {          //Executado quando a autenticação ocorrer com sucesso
    Serial.println("Auth OK! Ready to use...");
    printMessage("BEM-VINDO(A) AO", name);
    AuthOk = true;
  }
}


void readTCPStream() { //lê o JSON enviado pelo servidor e armazena num array de char para ser tratado pela lib
  char stream[128]; //também trata as mensagens recebidas direcionando para cada função específica
  bool flag = false;
  int j = 0;
  if (client.available()) {                       //Limpa o array da mensagem
    for (int i = 0; i < 128; i++)
      stream[i] = (char)0;
  }
  while (client.available() && !flag) {           //Armazena no array o conteudo recebido do servidor
    stream[j] = client.read();
    char lastChar = stream[j];
    j++;
    if (client.available() == 0 || lastChar == 125) // 125 --> }
      flag = !flag;
  }
  if (flag) {                                     //Executado quando a variável flag é verdadeira, ou seja, quando há conteúdo lido
    Serial.println(stream);
    StaticJsonBuffer<200> jsonBuffer;
    JsonObject& root = jsonBuffer.parseObject(stream);
    const char* type = root["type"];
    if (strcmp(type, "conn") == 0) {              //Trata mensagens do tipo 'conn'
      const char* auth = root["auth"];
      const char* name = root["name"];
      welcomeName = name;
      handleConnEvents(auth, name);
    }
    if (strcmp(type, "ping") == 0) {              //Trata os ping's enviados pelo servidor e responde
      client.print("{\"type\":\"pong\"}");
    }
    if (strcmp(type, "auth") == 0) {              //Trata mensagens do tipo 'auth'
      const char* auth = root["auth"];
      if (strcmp(auth, "ok") == 0) {                  //Executado se a autenticação foi feita com sucesso
        const char* name = root["name"];
        int admin = root["admin"];
        openMenu(name, admin);
        waitingResponse = false;
        fullCircle = true;
      }
      else if (strcmp(auth, "fail") == 0) {           //Executado se a autenticação não foi feita com sucesso
        Serial.println("AUTH FAIL");
        printMessage("USUARIO NAO", "AUTORIZADO");
        redColorAlert();
        waitingResponse = false;
        fullCircle = true;
      }
    }
    if (strcmp(type, "register") == 0) {              //Trata mensagens do tipo 'register'
      int id = root["id"];
      registerFinger(id);
      waitingResponse = false;
      fullCircle = true;
      lcd.clear();
      lcd.setCursor(0, 0);
      lcd.print("SAIU. E AGORA?");


      if (AuthOk) {

        if (waitingKeyboard) {          //Função usada para o menu de administrador, ela recebe os comandos do teclado e executa uma função a

          char tecla = leitura();   //partir de uma tecla específica
          Serial.println(tecla);
          if (tecla == 3) {
            tecla = leitura();
            Serial.print("tecla: ");
            Serial.println(tecla);
            if (tecla == (char)49) {      //Se for pressionada a tecla 1, o relé é acionado.
              Serial.print("opendoor");
              Serial.print(tecla);
              openDoor();
              fullCircle = true;
            }
            if (tecla == (char)50) {
              registerFinger(0);        //Se for pressionada a tecla 2, a função de registro de usuário é chamada
            }
            waitingKeyboard = false;    //No final de cada ciclo acima, a variável de flag do teclado é setada como falsa.
          }
        }
        if (fullCircle && !waitingKeyboard && !waitingID) {
          lcd.clear(); // limpa o conteúdo no dysplay LCD
          lcd.setCursor(0, 0); // seta o cursor para: (coluna = 0, linha = 0)
          lcd.print("BEM-VINDO(A) AO");
          lcd.setCursor(0, 1); // seta para linha 1, ou seja, a linha de baixo
          lcd.print(welcomeName);
          fullCircle = false;
        }
        if (!waitingResponse && !waitingKeyboard && !waitingID) {   //Estado padrão da tranca, sempre executado enquanto a tranca estiver ociosa
          int fingerID = readFinger();
          if (fingerID) {
            sendFingerID(fingerID);
            waitingResponse = true;
          }
        }
      }













    }
    flag = false;
  }
}

void sendFingerID(int id) {             //Função que envia o ID lido pelo sensor
  if (id) {
    StaticJsonBuffer<64> jsonBuffer;
    JsonObject& root = jsonBuffer.createObject();
    root["type"] = "fingerid";
    root["id"] = id;
    char buffer[64];
    root.printTo(buffer, sizeof(buffer));
    client.print(buffer);
  }
}

void openDoor() {
  lcd.clear(); // limpa o conteúdo no dysplay LCD
  lcd.setCursor(0, 0); // seta o cursor para: (coluna = 0, linha = 0)
  lcd.print("BEM-VINDO(A)");
  lcd.setCursor(0, 1); // seta para linha 1, ou seja, a linha de baixo
  lcd.print(userName);
  digitalWrite(rele, HIGH);
  delay(500);
  digitalWrite(rele, LOW);
  greenColorAlert();
}

void openMenu(String name, int admin) {  //Menu do administrador
  userName = name;
  if (!admin)
    openDoor();
  else {
    printMessage("1- ENTRAR", "2- CADASTRAR");
    waitingKeyboard = true;
    blueColorAlert();
  }
}

void registerFinger(int id) {           //Função que envia o pedido de ID ao servidor e chama a função de cadastro do sensor com o ID recebido
  if (!waitingID) {
    client.write("{\"type\":\"addfinger\"}");
    waitingID = true;
  }
  else {
    waitingID = false;
    addFinger(id);
    lcd.clear();
    lcd.setCursor(0, 0);
    // lcd.print("SAIU. E AGORA?");
  }
}

char leitura() {
  char keypress;
  while (1) {
    keypress = kpd.getKey();// put value of key pressed in variable 'keypress'
    if (keypress != NO_KEY) {
      if (keypress != (char)49 && keypress != (char)50)
        leitura();
      else
        break;
    }
  }
  return keypress;
}

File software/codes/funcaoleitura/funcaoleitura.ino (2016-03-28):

#include <OnewireKeypad.h>

char KEYS[]= {
 '3','2','1',//'A',
 '6','5','4',//'B',
 '9','8','7',//'C',
 '#','0','*',//'D'
};

OnewireKeypad <Print, 12 > Keypad(Serial, KEYS, 4, 3, A3, 4700, 1000 );


void setup ()
{
 Serial.begin(115200);
 Keypad.SetHoldTime(100);  // Key held time in ms
 Keypad.SetDebounceTime(50); // Key Debounce time in ms
}


void loop() {

  char key = Keypad.Key_State();
  if(key==3){
    Serial.print("tecla: ");
    Serial.println((char)key);
    Serial.println(leitura());
    }

}

char leitura(){
  char keypress = Keypad.Getkey();  // put value of key pressed in variable 'keypress'
  while ((Keypad.Key_State())){}  // Stay here while Key is held down
  return keypress;
}

  

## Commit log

2015-09-15 Foi criado um diretório que contém os códigos de teste de cada componente do projeto
2015-09-15 atualização de repositório
    [SETBOARD.brd, SETBOARD.sch]
2015-09-16 nova versão de placa set shield e atualização do diretório test
    [SETBOARD.brd, SETBOARD.sch]
2015-09-16 Obs. no momento da importação de uma biblioteca para o arduino os arquivos compactados ou os folders devem conter somente letras em seu nome.
2015-09-18 atualização do código de teste keypad (correção de pinos). Atualização de diretório de servidor node para o setfinger
2015-09-23 criação das funções de adição e leitura de digitais para o sensor fingerprint e atualização de diretório documentation
2015-09-24 atualização de códigos de teste do sensor fingerprint. Os códigos atualizados contém as funções definitivas que serão utilizadas no desenvolvimento do código do setfinger
2015-09-24 atualização do código de teste do sensor fingerprint. Novo código completo com todas as funcionalidades integradas
2015-09-25 atualização de código tests>fingerprint
2015-09-28 atualização do código de teste do teclado. reconfiguração da pinagem
2015-10-15 atualização de códigos arduino (pinagem)
    [SETBOARD.brd]
2015-11-13 atualização de código setfinger
2015-12-16 atualização de código node
2016-03-11 atualização esquemáticos (hardware)
    [SETBOARD.brd, SETBOARD.sch]
2016-03-23 código setfinger utilizando protocolo de comunicação i2c
2016-03-28 atualização código setfinger i2c - teclado funcionando
2016-03-28 correção de bug teclado i2c
    [setfinger_i2c.ino]
2016-03-29 atualização código setfinger i2c - sem tempo de espera para retirar o dedo na hora do cadastro
2016-03-29 atualização código setSERVER - registro de nomes no registro de acessos (history)
2016-03-31 Adição de nova placa setshiedl - i2c
    [Esquematico.brd, Esquematico.sch]
2016-04-01 atualização código Setfinger-i2c
2016-04-27 Modificação na função leitura
    com a utilização do chip I²C PCF8574 para controlar nosso teclado, nossas funções de leitura de entradas do teclado matricial fora alteradas.

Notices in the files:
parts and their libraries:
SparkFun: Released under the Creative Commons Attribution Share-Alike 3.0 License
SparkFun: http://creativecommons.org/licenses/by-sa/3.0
